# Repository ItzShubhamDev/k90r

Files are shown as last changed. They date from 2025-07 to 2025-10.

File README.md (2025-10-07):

# K90R

A Custom 90 Keys Keyboard including Rotary Encoder Switch, OLED powered by Rasberry Pi Pico MCU and KMK Firmware.

## Features

-   Per-Key RGB LED
-   Hotswap Sockets
-   OLED Display
-   Rotary Encoder

## Bill of Materials

| Name | Quantity | Pack Of | Price (INR) | Cost (INR) | Cost (USD) | Source |
| --- | --- | --- | --- | --- | --- | --- |
| Akko V3 Cream Black Pro Switch | 90 | 45 | 899 | 1798 | 20.677 | [StacksKB](https://stackskb.com/store/akko-v3-cream-blue-pro-switch-pack-of-45/) |
| Veekos Gradient Keycaps | 1 | 1 | 1299 | 1299 | 14.9385 | [StacksKB](https://stackskb.com/store/veekos-gradient-keycaps-cherry-profile-135-keys/) |
| Durock Smokey Screw-In Stabilizers | 1 | 1 | 1595 | 1595 | 18.3425 | [StacksKB](https://stackskb.com/store/durock-smokey-screw-in-stabilizers-v2/) |
| Gateron Hotswap Sockets | 90 | 1 | 10 | 900 | 10.35 | [StacksKB](https://stackskb.com/store/gateron-hotswap-sockets/) |
| 1N4148 Diode | 100 | 100 | 99 | 99 | 1.1385 | [Makerbazar](https://makerbazar.in/products/dip-rectifier-diode-through-hole?variant=46889718120688) |
| Raspberry Pi Pico | 1 | 1 | 399 | 399 | 4.5885 | [Makerbazar](https://makerbazar.in/products/raspberry-pi-pico-development-boards?variant=47233117356272) |
| 0.91 Inch OLED Display | 1 | 1 | 229 | 229 | 2.6335 | [Makerbazar](https://makerbazar.in/products/0-91-inch-i2c-iic-serial-4-pin-oled-display-module-blue?variant=45428382400752) |
| Rotary Encoder Module | 1 | 1 | - | - | | Self |
| SK6812MINI-E | 90 | 1 | 6 | 540 | 6.21 | [LCSC](https://lcsc.com/product-detail/RGB-LEDs-Built-in-IC_OPSCO-Optoelectronics-SK6812MINI-E_C5149201.html) |
| PCB (Option A) | 1 | 1 | 5429 | 5429 | 62.4335 | [PCBPower](https://www.pcbpower.com/page/pcb-fabrication) |
| PCB (Option B) | 1 | 1 | 5325 | 5325 | 61.2375 | [JLCPCB](https://jlcpcb.com/) |
| PCB (Option C) | 1 | 1 | 8245 | 8245 | 94.8175 | [LionCircuits](https://www.lioncircuits.com/) |
| PCB (Option D) | 1 | 1 | 5468 | 5468 | 62.882 | [Robu](https://robu.in/product/online-pcb-manufacturing-service) |
| 4.7 k Resistor | 2 | 1 | - | - | | Self |
| 0.1 µF Capacitor | 1 | 1 | - | - | | Self |
| Allen CSK M3 Screw 30mm | 5 | 1 | 11 | 55 | 0.6325 | [Novo3D](https://novo3d.in/allen-csk-screw/) |
| Allen CSK M3 Screw 25mm | 2 | 1 | 9 | 18 | 0.207 | [Novo3D](https://novo3d.in/allen-bolt-cs/) |
| Allen Bolt M3 Screw 20mm | 2 | 1 | 7 | 14 | 0.161 | [Novo3D](https://novo3d.in/allen-csk-screw/) |
| Allen CSK M3 Screw 16mm | 5 | 1 | 7 | 35 | 0.4025 | [Novo3D](https://novo3d.in/allen-csk-screw/) |
| Brass Heat Set M3 6mm | 14 | 1 | 3 | 42 | 0.483 | [Novo3D](https://novo3d.in/brass-heat-set/) |
| 3D Printed Bottom | 1 | 1 | - | - | | Printlegion |
| 3D Printed Top | 1 | 1 | - | - | | Printlegion |
| 3D Printed Plate | 1 | 1 | - | - | | Printlegion |
| Shipping Charge Amazon | 1 | 1 | 100 | 100 | 1.15 | [Amazon](https://amzn.in/) |
| Shipping + Handling LCSC | 1 | 1 | 590 | 590 | 6.785 | [LCSC](https://lcsc.com/) |
| Misc. | 1 | 1 | 200 | 200 | 2.3 | |
| **Total** | | | | 13381 | 153.8815 | |

## Keyboard

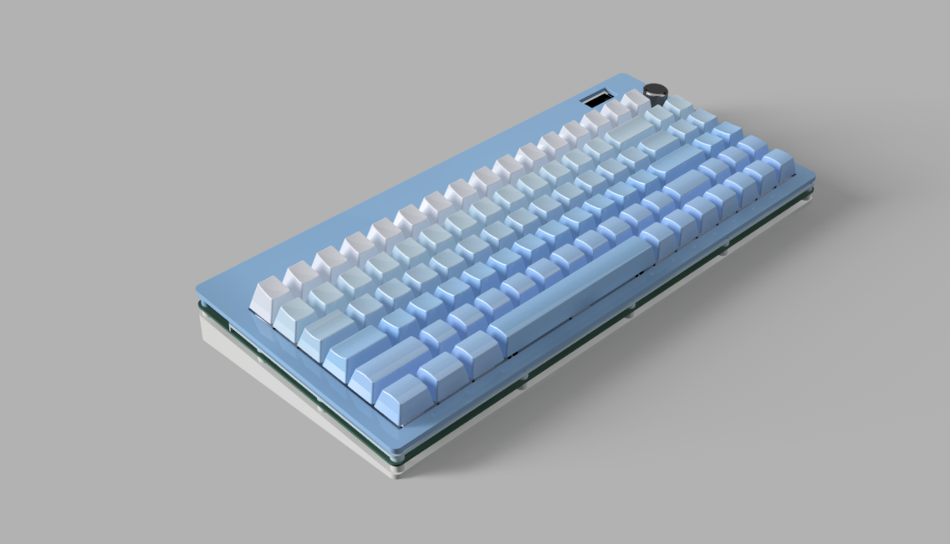
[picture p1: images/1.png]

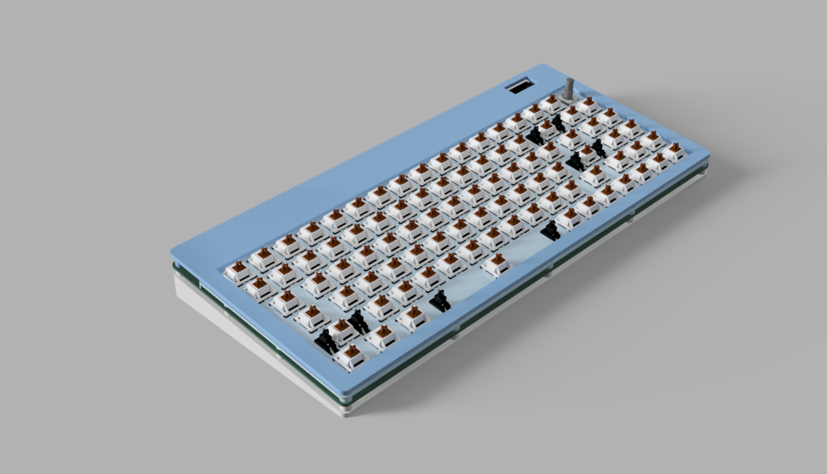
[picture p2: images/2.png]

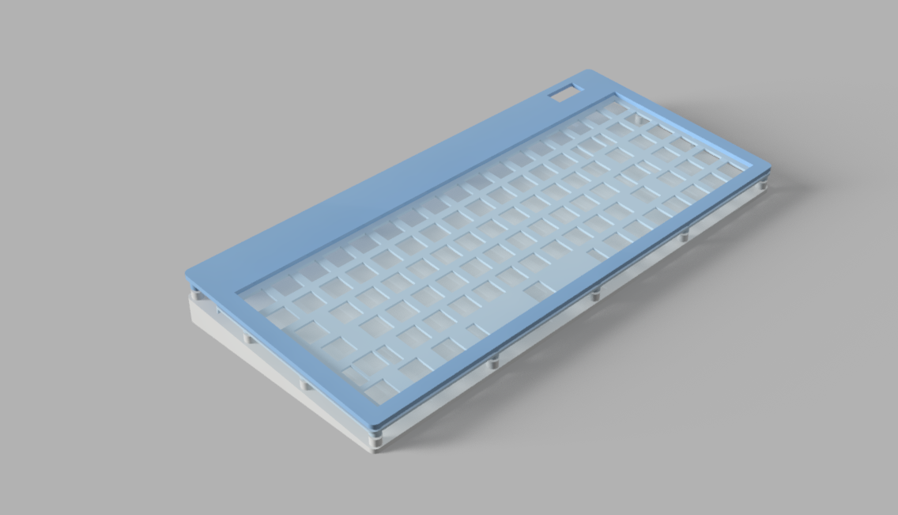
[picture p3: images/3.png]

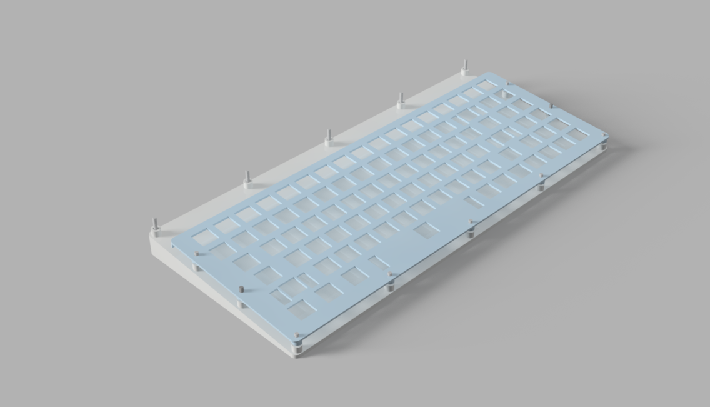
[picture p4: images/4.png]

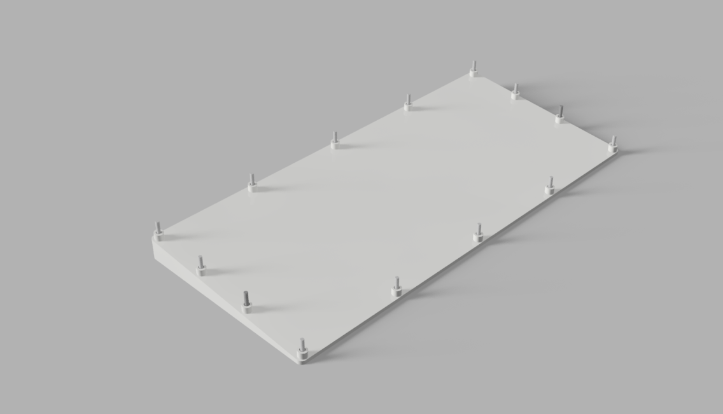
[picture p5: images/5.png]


## SideView

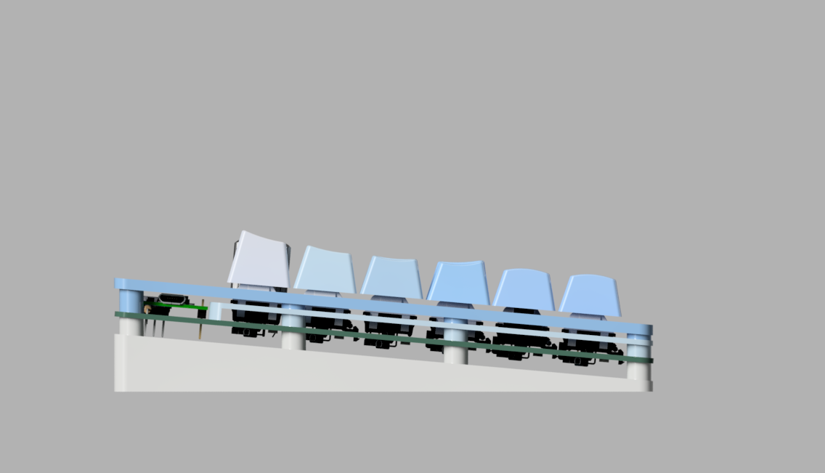
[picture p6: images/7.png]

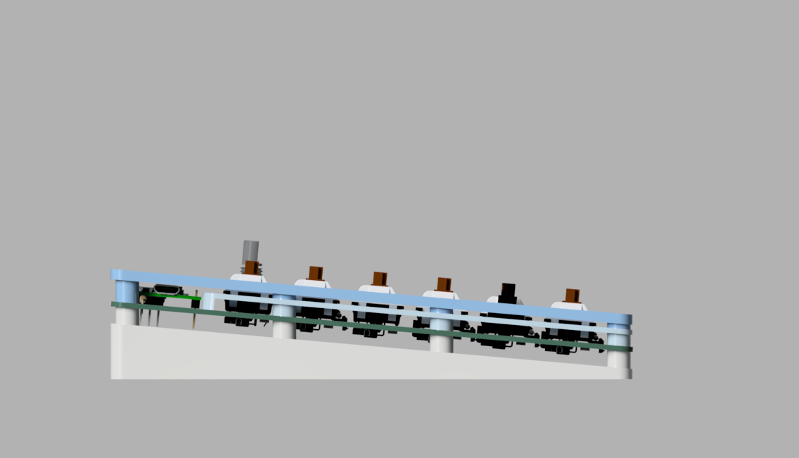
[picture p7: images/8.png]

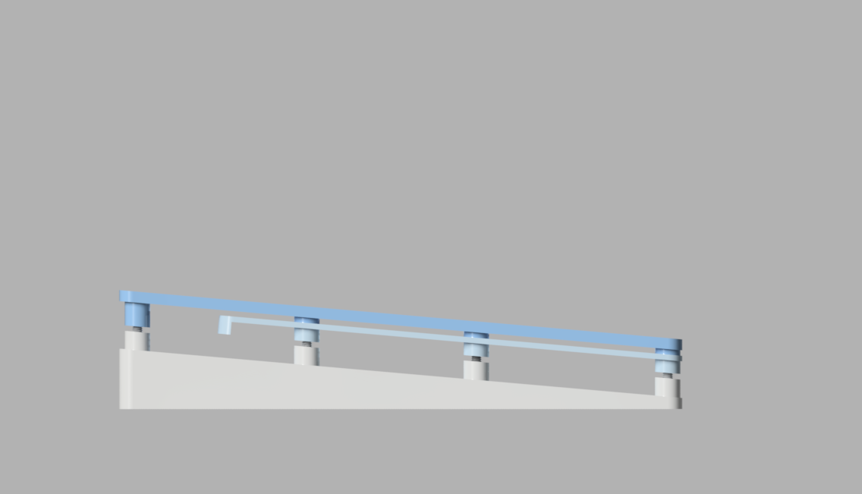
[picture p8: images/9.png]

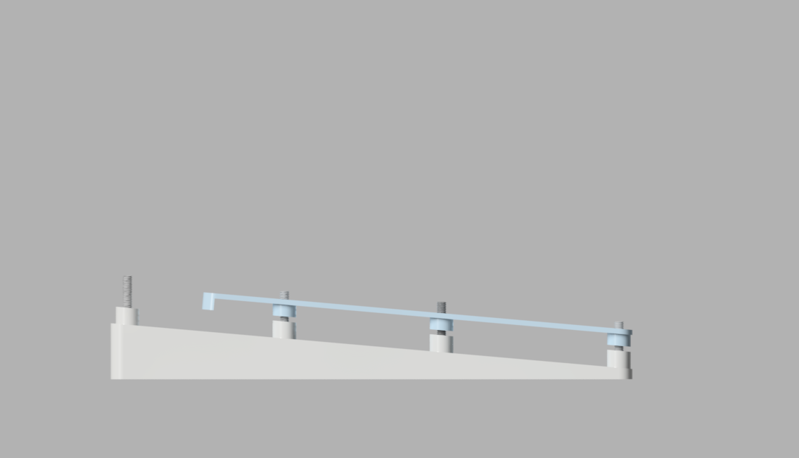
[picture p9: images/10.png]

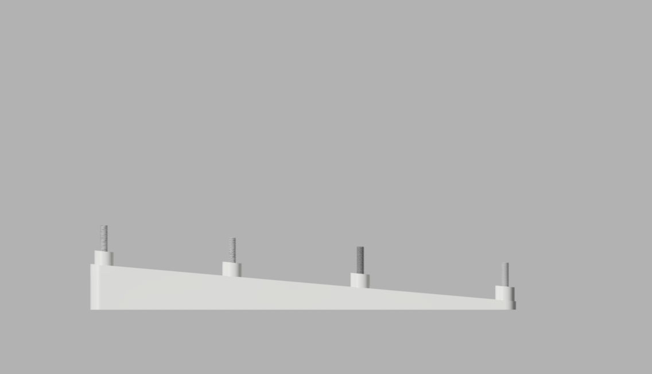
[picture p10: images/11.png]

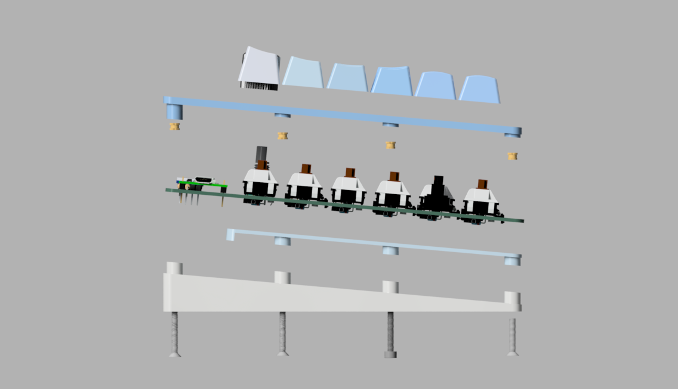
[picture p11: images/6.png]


## Circuit

### Schematic

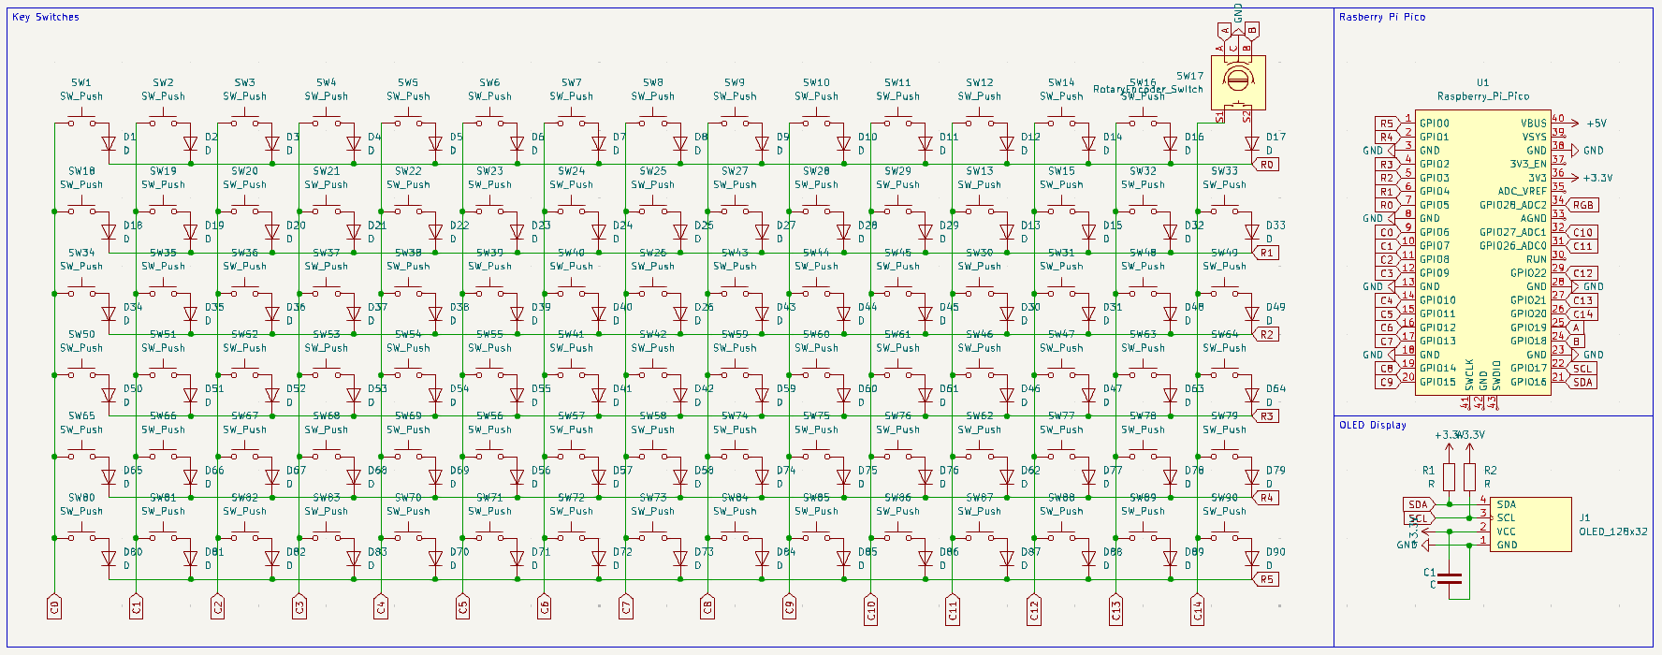
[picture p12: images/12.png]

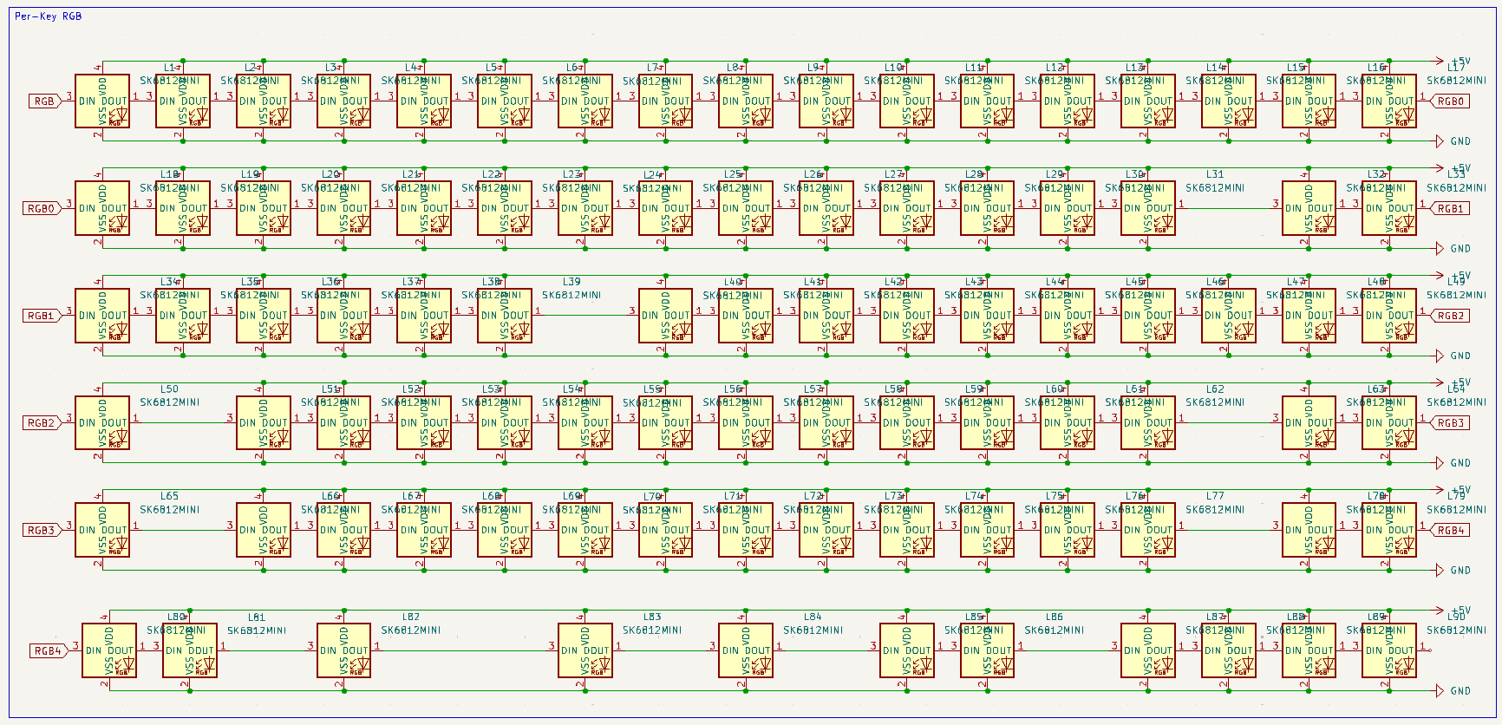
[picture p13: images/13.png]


### PCB

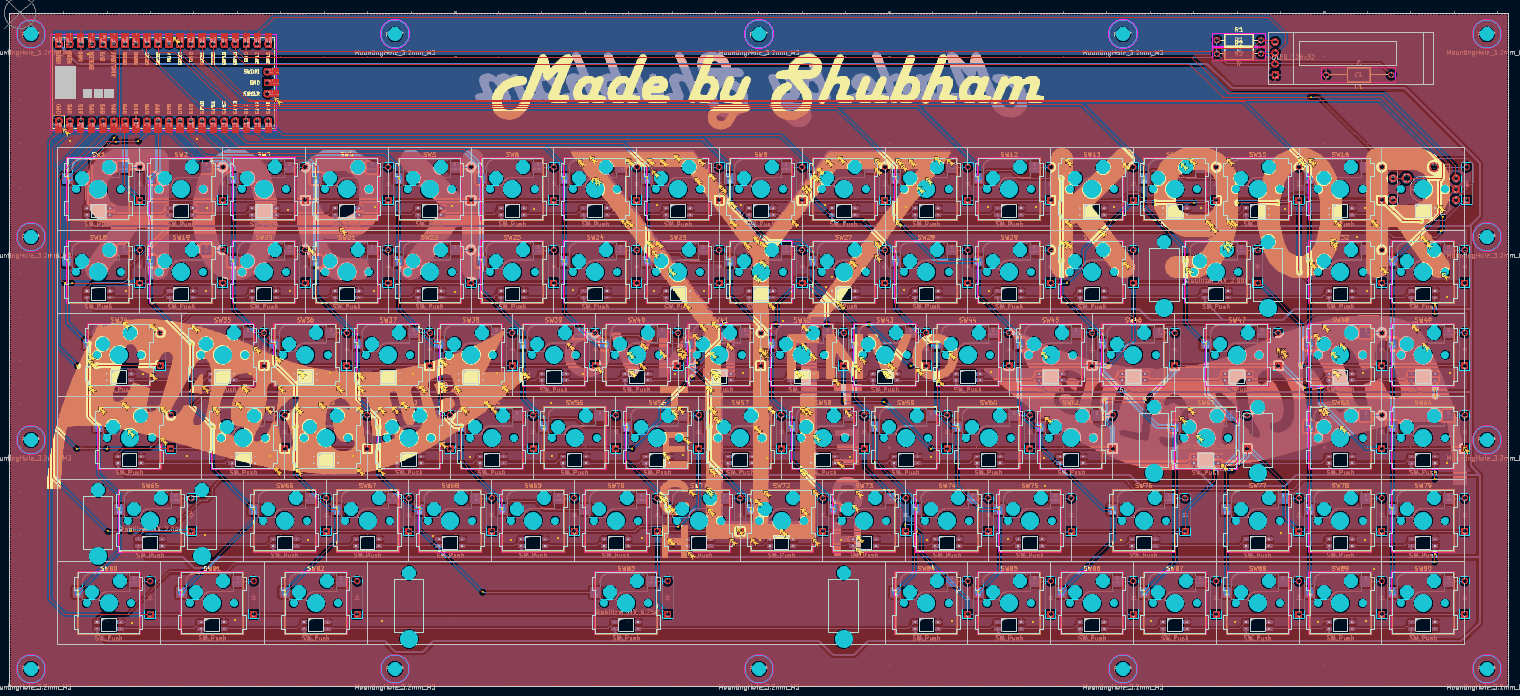
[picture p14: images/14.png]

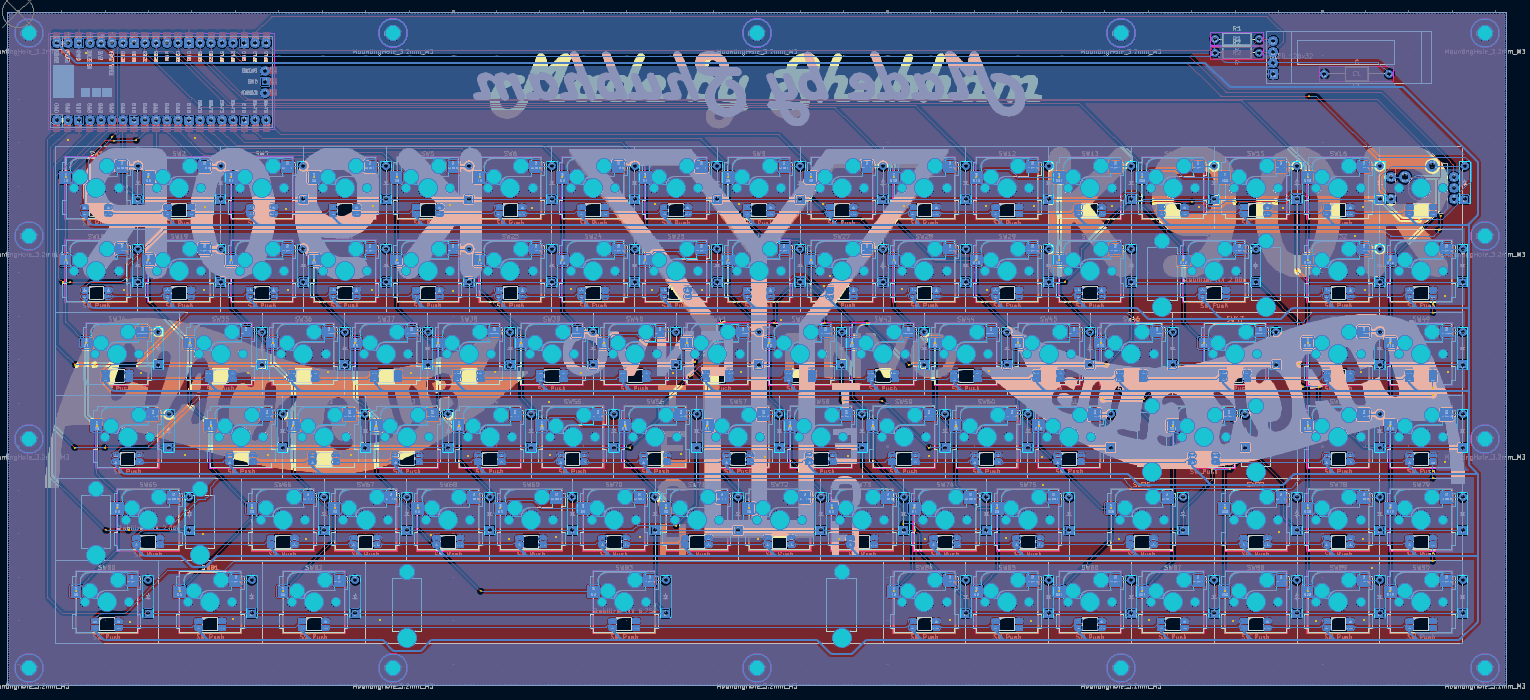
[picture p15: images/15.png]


### 3D

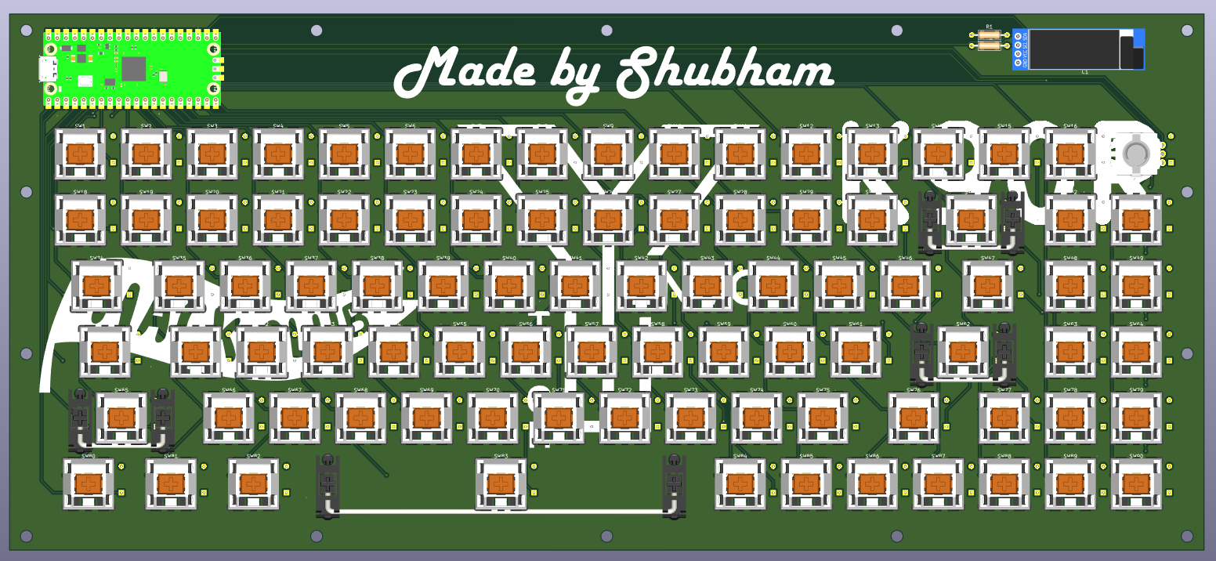
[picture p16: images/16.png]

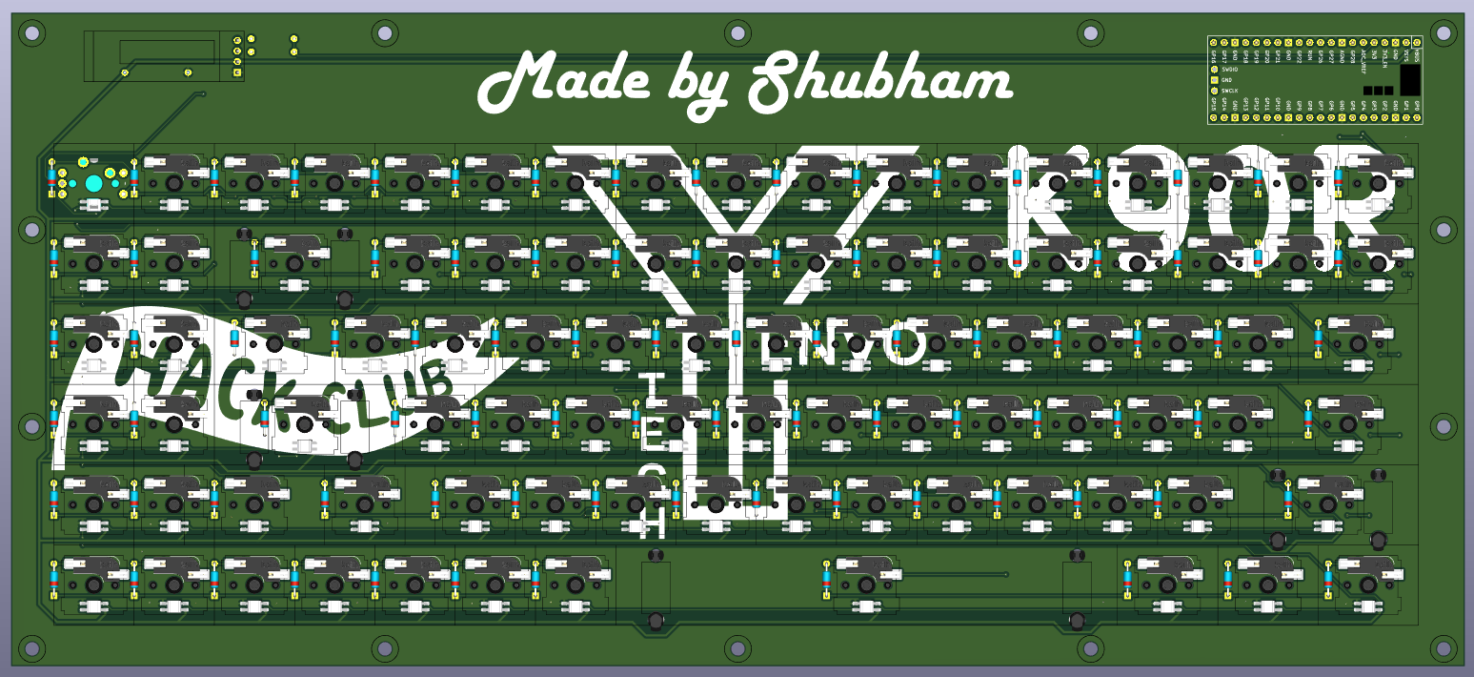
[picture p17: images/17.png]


## Additional Information

-   **Firmware**: [KMK](https://github.com/KMKfw/kmk_firmware/)
-   **Symbols and FootPrints**: [ScottoKicad](https://github.com/joe-scotto/scottokeebs/tree/main/Extras/ScottoKicad)
-   **PCB Software**: [Kicad](https://www.kicad.org/)
-   **3D Design Software**: [Autodesk Fusion 360](https://www.autodesk.com/in/products/fusion-360/overview)

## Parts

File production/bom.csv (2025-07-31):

Designator | Footprint | Quantity | Value | LCSC Part #
C1 | C_Axial_L5.1mm_D3.1mm_P15.00mm_Horizontal | 1 | C
D1, D10, D11, D12, D13, D14, D15, D16, D17, D18, D19, D2, D20, D21, D22, D23, D24, D25, D26, D27, D28, D29, D3, D30, D31, D32, D33, D34, D35, D36, D37, D38, D39, D4, D40, D41, D42, D43, D44, D45, D46, D47, D48, D49, D5, D50, D51, D52, D53, D54, D55, D56, D57, D58, D59, D6, D60, D61, D62, D63, D64, D65, D66, D67, D68, D69, D7, D70, D71, D72, D73, D74, D75, D76, D77, D78, D79, D8, D80, D81, D82, D83, D84, D85, D86, D87, D88, D89, D9, D90 | Diode_DO-35 | 90 | D
J1 | OLED_128x32 | 1 | OLED_128x32
L1, L10, L11, L12, L13, L14, L15, L16, L17, L18, L19, L2, L20, L21, L22, L23, L24, L25, L26, L27, L28, L29, L3, L30, L31, L32, L33, L34, L35, L36, L37, L38, L39, L4, L40, L41, L42, L43, L44, L45, L46, L47, L48, L49, L5, L50, L51, L52, L53, L54, L55, L56, L57, L58, L59, L6, L60, L61, L62, L63, L64, L65, L66, L67, L68, L69, L7, L70, L71, L72, L73, L74, L75, L76, L77, L78, L79, L8, L80, L81, L82, L83, L84, L85, L86, L87, L88, L89, L9, L90 | LED_SK6812MINI | 90 | SK6812MINI
R1, R2 | R_Axial_DIN0207_L6.3mm_D2.5mm_P10.16mm_Horizontal | 2 | R
SW1, SW10, SW11, SW12, SW13, SW14, SW15, SW16, SW18, SW19, SW2, SW20, SW21, SW22, SW23, SW24, SW25, SW26, SW27, SW28, SW29, SW3, SW30, SW32, SW33, SW35, SW36, SW37, SW38, SW39, SW4, SW40, SW41, SW42, SW43, SW44, SW45, SW46, SW48, SW49, SW5, SW51, SW52, SW53, SW54, SW55, SW56, SW57, SW58, SW59, SW6, SW60, SW61, SW63, SW64, SW66, SW67, SW68, SW69, SW7, SW70, SW71, SW72, SW73, SW74, SW75, SW77, SW78, SW79, SW8, SW84, SW85, SW86, SW87, SW88, SW89, SW9, SW90 | Hotswap_MX_1.00u | 78 | SW_Push
SW17 | Encoder_EC11_MX_Combo_1 | 1 | RotaryEncoder_Switch
SW31 | Hotswap_MX_2.00u | 1 | SW_Push
SW34, SW47 | Hotswap_MX_1.50u | 2 | SW_Push
SW50, SW76 | Hotswap_MX_1.75u | 2 | SW_Push
SW62, SW65 | Hotswap_MX_2.25u | 2 | SW_Push
SW80, SW81, SW82 | Hotswap_MX_1.25u | 3 | SW_Push
SW83 | Hotswap_MX_6.25u | 1 | SW_Push
U1 | Raspberry_Pi_Pico | 1 | Raspberry_Pi_Pico

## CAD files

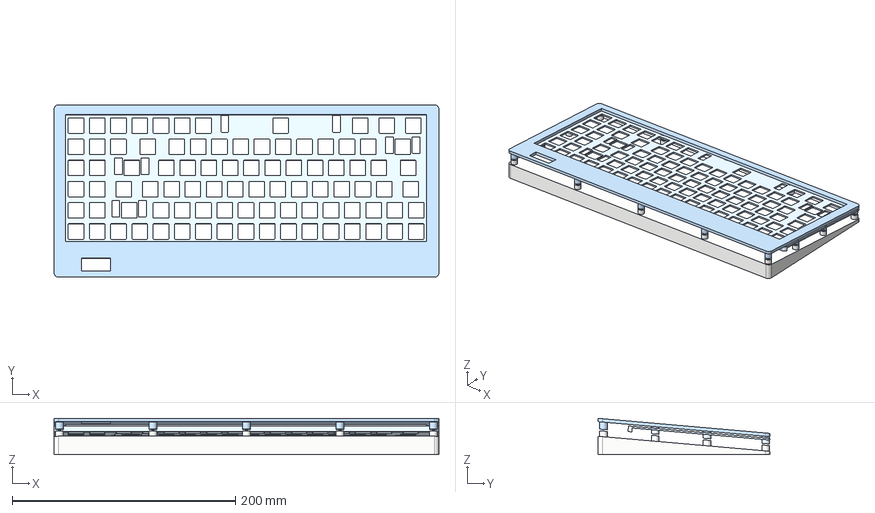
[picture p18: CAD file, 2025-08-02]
cad/Case.step
345.0 x 154.4 x 32.6 mm
Top
Base
Plate

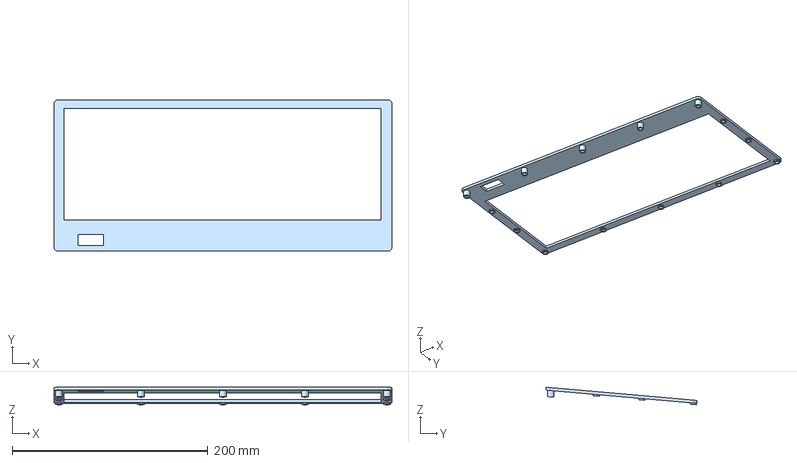
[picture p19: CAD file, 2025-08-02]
production/case/Top.step
345.0 x 154.4 x 18.0 mm

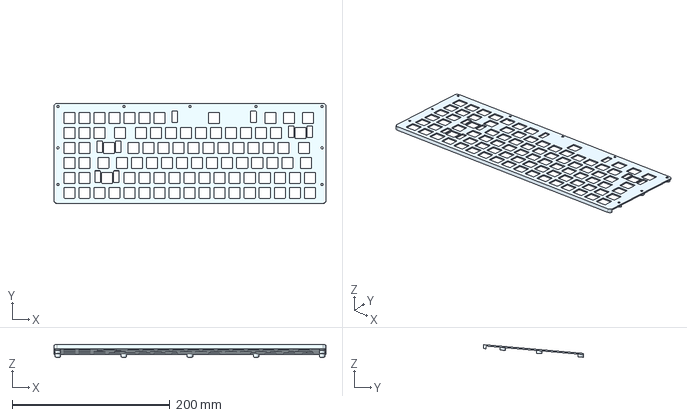
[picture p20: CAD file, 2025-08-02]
cad/Plate.step
345.0 x 127.4 x 16.1 mm

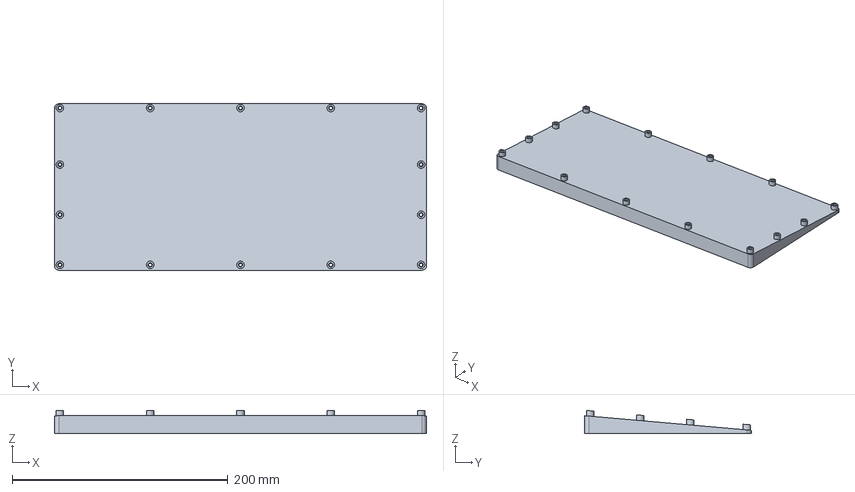
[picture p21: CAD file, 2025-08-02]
production/case/Base.step
345.0 x 154.4 x 21.4 mm

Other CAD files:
cad/Base.step
production/case/Base.stl
production/case/Plate.stl
production/case/Top.stl

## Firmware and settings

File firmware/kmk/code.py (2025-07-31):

import board
import busio
from adafruit_ssd1306 import SSD1306_I2C

from kmk.kmk_keyboard import KMKKeyboard
from kmk.keys import KC
from kmk.scanners import DiodeOrientation
from kmk.scanners.keypad import KeysScanner

from kmk.modules.layers import Layers
from kmk.modules.macros import Press, Release, Tap, Macros
from kmk.modules.encoder import EncoderHandler
from kmk.modules.rgb import RGB
from kmk.extensions.media_keys import MediaKeys

keyboard = KMKKeyboard()
i2c = busio.I2C(board.SCL, board.SDA)

class Display(SSD1306_I2C):
    def on_layer_change(self, layer: int):
        self.fill(0)
        self.text(f'K90R - {layer}', 0, 0, 1)
        self.show()

display = Display(128, 32, i2c)  
keyboard.extensions.append(display)  

keyboard.row_pins = (board.GP5, board.GP4, board.GP3, board.GP2, board.GP1, board.GP0)
keyboard.col_pins = (
    board.GP6, board.GP7, board.GP8, board.GP9, board.GP10,
    board.GP11, board.GP12, board.GP13, board.GP14, board.GP15,
    board.GP27, board.GP26, board.GP22, board.GP21, board.GP20
)
keyboard.diode_orientation = DiodeOrientation.COL2ROW

encoder_handler = EncoderHandler()
macros = Macros()
encoder_handler.pins = ((board.GP19, board.GP18, None))

keyboard.modules.append(macros)
keyboard.modules.append(Layers())
keyboard.modules.append(encoder_handler)
keyboard.extensions.append(MediaKeys())

rgb = RGB(pixel_pin=board.GP28, num_pixels=90)
keyboard.extensions.append(rgb)

keyboard.keymap = [
  # Layer 0: Default Layer
  [
    KC.ESC, KC.F1,  KC.F2,  KC.F3,  KC.F4,  KC.F5,  KC.F6,  KC.F7,  KC.F8,  KC.F9,  KC.F10, KC.F11, KC.F12, KC.PSCR, KC.PAUS, KC.DEL, KC.MUTE,
    KC.GRAVE, KC.N1, KC.N2, KC.N3, KC.N4, KC.N5, KC.N6, KC.N7, KC.N8, KC.N9, KC.N0, KC.MINS, KC.EQL, KC.BSPC, KC.HOME, KC.MPLY,
    KC.TAB, KC.Q, KC.W, KC.E, KC.R, KC.T, KC.Y, KC.U, KC.I, KC.O, KC.P, KC.LBRC, KC.RBRC, KC.PGUP, KC.END, KC.MNXT,
    KC.CAPS, KC.A, KC.S, KC.D, KC.F, KC.G, KC.H, KC.J, KC.K, KC.L, KC.SCLN, KC.QUOT, KC.ENT, KC.PGDN, KC.MPRV,
    KC.LSFT, KC.Z, KC.X, KC.C, KC.V, KC.B, KC.N, KC.M, KC.COMM, KC.DOT, KC.SLSH, KC.RSFT, KC.UP, KC.MSTP,
    KC.LCTL, KC.LGUI, KC.LALT, KC.SPC, KC.RALT, KC.MO(1), KC.RCTL, KC.LEFT, KC.DOWN, KC.RIGHT, KC.LT(2, KC.RGB_TOG)
  ],
  # Layer 1: Function layer - Yet to be defined
  [
    KC.ESC, KC.F1, KC.F2, KC.F3,  KC.F4,  KC.F5,  KC.F6,  KC.F7,  KC.F8,  KC.F9,  KC.F10, KC.F11, KC.F12, KC.PSCR, KC.PAUS, KC.DEL, KC.MUTE,
    KC.GRAVE, KC.N1, KC.N2, KC.N3, KC.N4, KC.N5, KC.N6, KC.N7, KC.N8, KC.N9, KC.N0, KC.MINS, KC.EQL, KC.BSPC, KC.HOME, KC.MPLY,
    KC.TAB, KC.Q, KC.W, KC.E, KC.R, KC.T, KC.Y, KC.U, KC.I, KC.O, KC.P, KC.LBRC, KC.RBRC, KC.PGUP, KC.END, KC.MNXT,
    KC.CAPS, KC.A, KC.S, KC.D, KC.F, KC.G, KC.H, KC.J, KC.K, KC.L, KC.SCLN, KC.QUOT, KC.ENT, KC.PGDN, KC.MPRV,
    KC.LSFT, KC.Z, KC.X, KC.C, KC.V, KC.B, KC.N, KC.M, KC.COMM, KC.DOT, KC.SLSH, KC.RSFT, KC.UP, KC.MSTP,
    KC.LCTL, KC.LGUI, KC.LALT, KC.SPC, KC.RALT, KC.MO(1), KC.RCTL, KC.LEFT, KC.DOWN, KC.RIGHT, KC.LT(2, KC.RGB_TOG)
  ],
  # Layer 2: LED Control Layer
  [
    KC.ESC, KC.F1, KC.F2, KC.F3,  KC.F4,  KC.F5,  KC.F6,  KC.F7,  KC.F8,  KC.F9,  KC.F10, KC.F11, KC.F12, KC.PSCR, KC.PAUS, KC.DEL, KC.RGB_MODE_PLAIN,
    KC.GRAVE, KC.N1, KC.N2, KC.N3, KC.N4, KC.N5, KC.N6, KC.N7, KC.N8, KC.N9, KC.N0, KC.MINS, KC.EQL, KC.BSPC, KC.HOME, KC.RGB_HUI,
    KC.TAB, KC.Q, KC.W, KC.E, KC.R, KC.T, KC.Y, KC.U, KC.I, KC.O, KC.P, KC.LBRC, KC.RBRC, KC.PGUP, KC.END, KC.RGB_HUD,
    KC.CAPS, KC.A, KC.S, KC.D, KC.F, KC.G, KC.H, KC.J, KC.K, KC.L, KC.SCLN, KC.QUOT, KC.ENT, KC.PGDN, KC.RGB_SAI,
    KC.LSFT, KC.Z, KC.X, KC.C, KC.V, KC.B, KC.N, KC.M, KC.COMM, KC.DOT, KC.SLSH, KC.RSFT, KC.UP, KC.RGB_SAD,
    KC.LCTL, KC.LGUI, KC.LALT, KC.SPC, KC.RALT, KC.MO(1), KC.RCTL, KC.LEFT, KC.DOWN, KC.RIGHT, KC.LT(2, KC.RGB_TOG)
  ]
]

rgb_modes = [
    KC.RGB_MODE_BREATHE,
    KC.RGB_MODE_RAINBOW,
    KC.RGB_MODE_BREATHE_RAINBOW,
    KC.RGB_MODE_KNIGHT,
    KC.RGB_MODE_SWIRL,
]

current_mode = 0

def rgb_mode_change(clockwise=False):
    global current_mode
    
    if clockwise:
      current_mode = current_mode + 1 if current_mode < len(rgb_modes) - 1 else 0
    else:
      current_mode = current_mode - 1 if current_mode > 0 else len(rgb_modes) - 1

    return Tap(rgb_modes[current_mode])

encoder_handler.map = [
  [
    KC.VOLD, KC.VOLU
  ],
  [
    KC.VOLD, KC.VOLU
  ],
  [
    rgb_mode_change(True), rgb_mode_change()
  ]
]

display.fill(0)
display.text('K7R', 0, 0, 1)
display.show()

if __name__ == '__main__':
    keyboard.go()

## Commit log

2025-07-31 Add keyboard files
    [Base.step, Keyboard.kicad_sch, bom.csv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]
2025-07-31 Change OLED input to 3.3v
    [Keyboard.kicad_sch, bom.csv]
2025-08-02 Fix Rotary Encoder and add missing files
    [Base.step, Base.stl, Case.step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]
2025-10-07 Updated the Bill of Materials
2025-10-07 Update BOM.
    [bom.csv]
